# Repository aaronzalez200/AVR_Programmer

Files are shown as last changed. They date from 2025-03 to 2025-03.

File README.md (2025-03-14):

# AVR_Programmer

Small board with mounting holes that was designed to easily place an Arduino that runs software that programs an external board that contains an AVR chip via ICSP. Display included to show the user the testing process and if any errors have occurred.

Designed using KiCad

BoardTop
BoardBottom

Early prototype using Arduino MEGA later updated for UNO:

Screenshot_20250314_091232_Gallery

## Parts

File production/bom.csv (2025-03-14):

Designator | Footprint | Quantity | Value | LCSC Part #
A1 | Arduino_UNO_R3 | 1 | Arduino_UNO_R3
C1, C2 | C_Axial_L3.8mm_D2.6mm_P7.50mm_Horizontal | 2 | 0.1uF
H1, H2, H3, H4 | MountingHole_3mm | 4 | MountingHole
H5, H6, H7, H8 | Display_Mounting_Hole | 4 | Display Mounting
J1 | PinHeader_1x20_P2.54mm_Vertical | 1 | NHD-2.23-12832UCB3
J2 | IDC-Header_2x03_P2.54mm_Vertical | 1 | Programming Header
R1 | R_Axial_DIN0411_L9.9mm_D3.6mm_P12.70mm_Horizontal | 1 | 1k
R2 | R_Axial_DIN0411_L9.9mm_D3.6mm_P12.70mm_Horizontal | 1 | 10k
SW1 | TerminalBlock_bornier-2_P5.08mm | 1 | Button
U1 | TSSOP24_SOT355-1_NXP | 1 | NVT2010PW_118

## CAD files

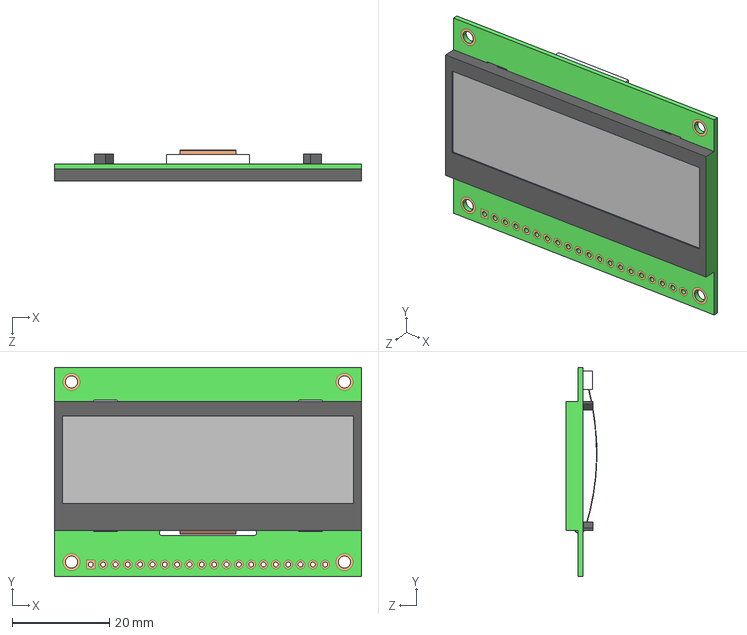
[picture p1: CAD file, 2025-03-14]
LibrariesAdded/NHD-2.23-12832U/NHD-2.23-12832U.STEP
63.2 x 43.1 x 6.37 mm

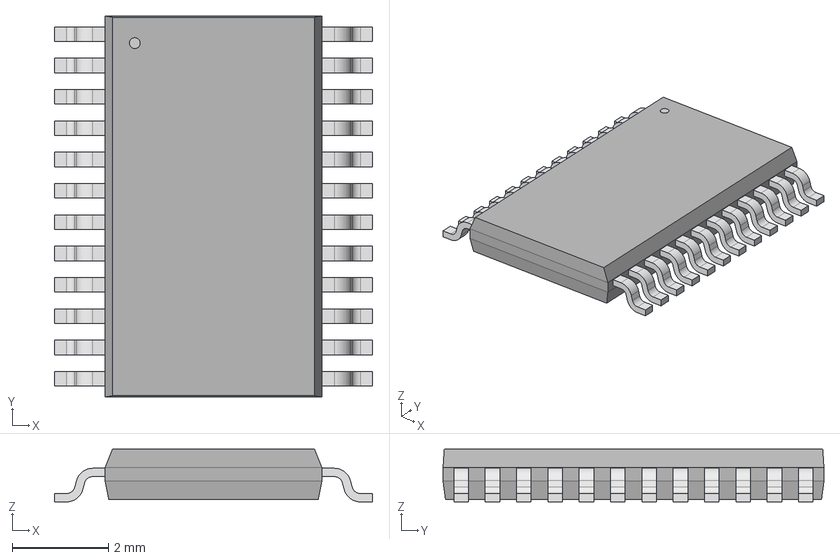
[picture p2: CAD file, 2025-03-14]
LibrariesAdded/NVT2010PW_118/TSSOP24_SOT355-1_NXP.step
6.60 x 7.90 x 1.09 mm

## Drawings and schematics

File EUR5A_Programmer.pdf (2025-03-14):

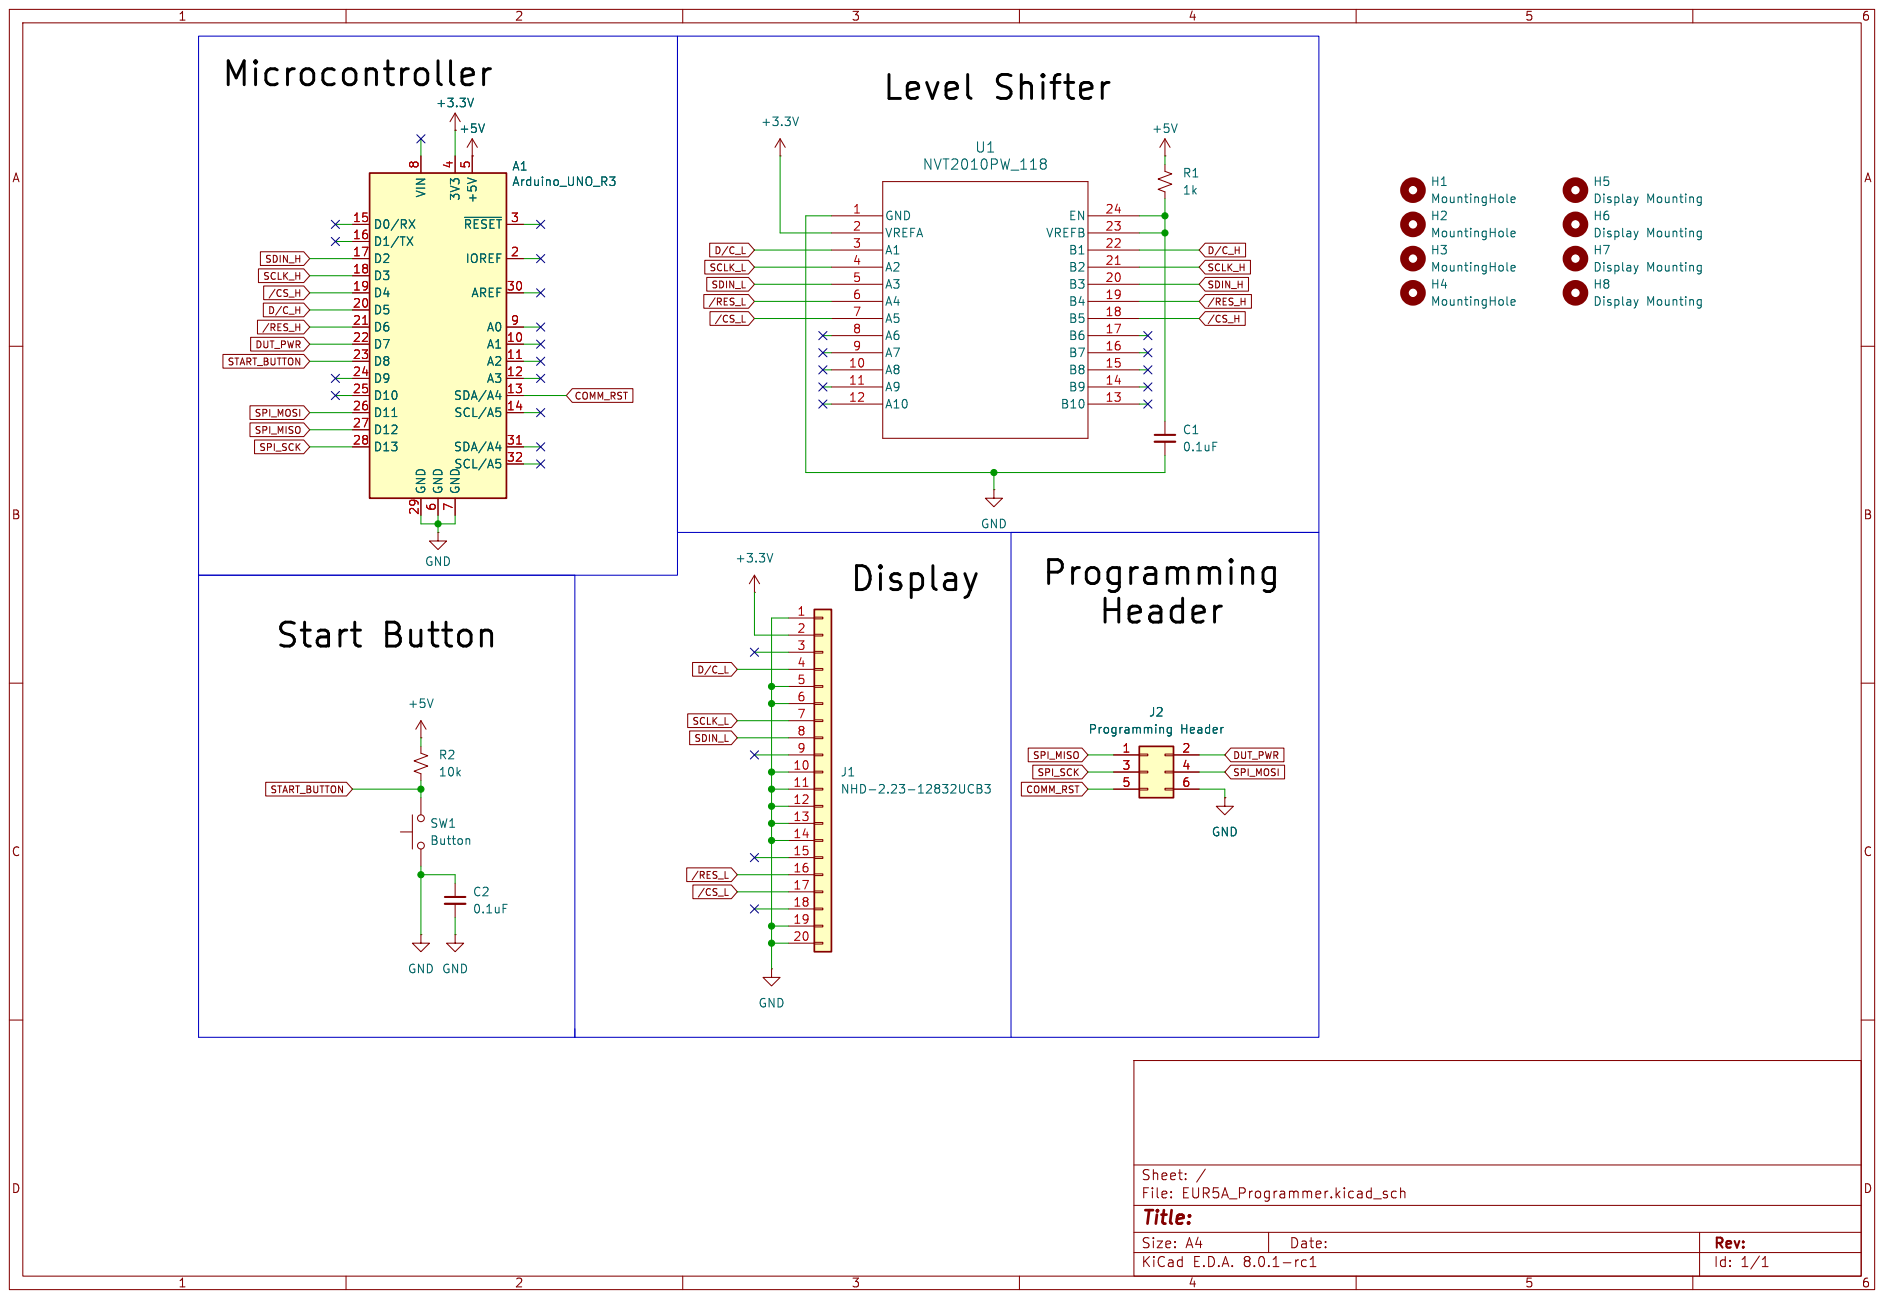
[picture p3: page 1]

Id: 1/1 Title: File: EUR5A_Programmer.kicad_sch Sheet: /

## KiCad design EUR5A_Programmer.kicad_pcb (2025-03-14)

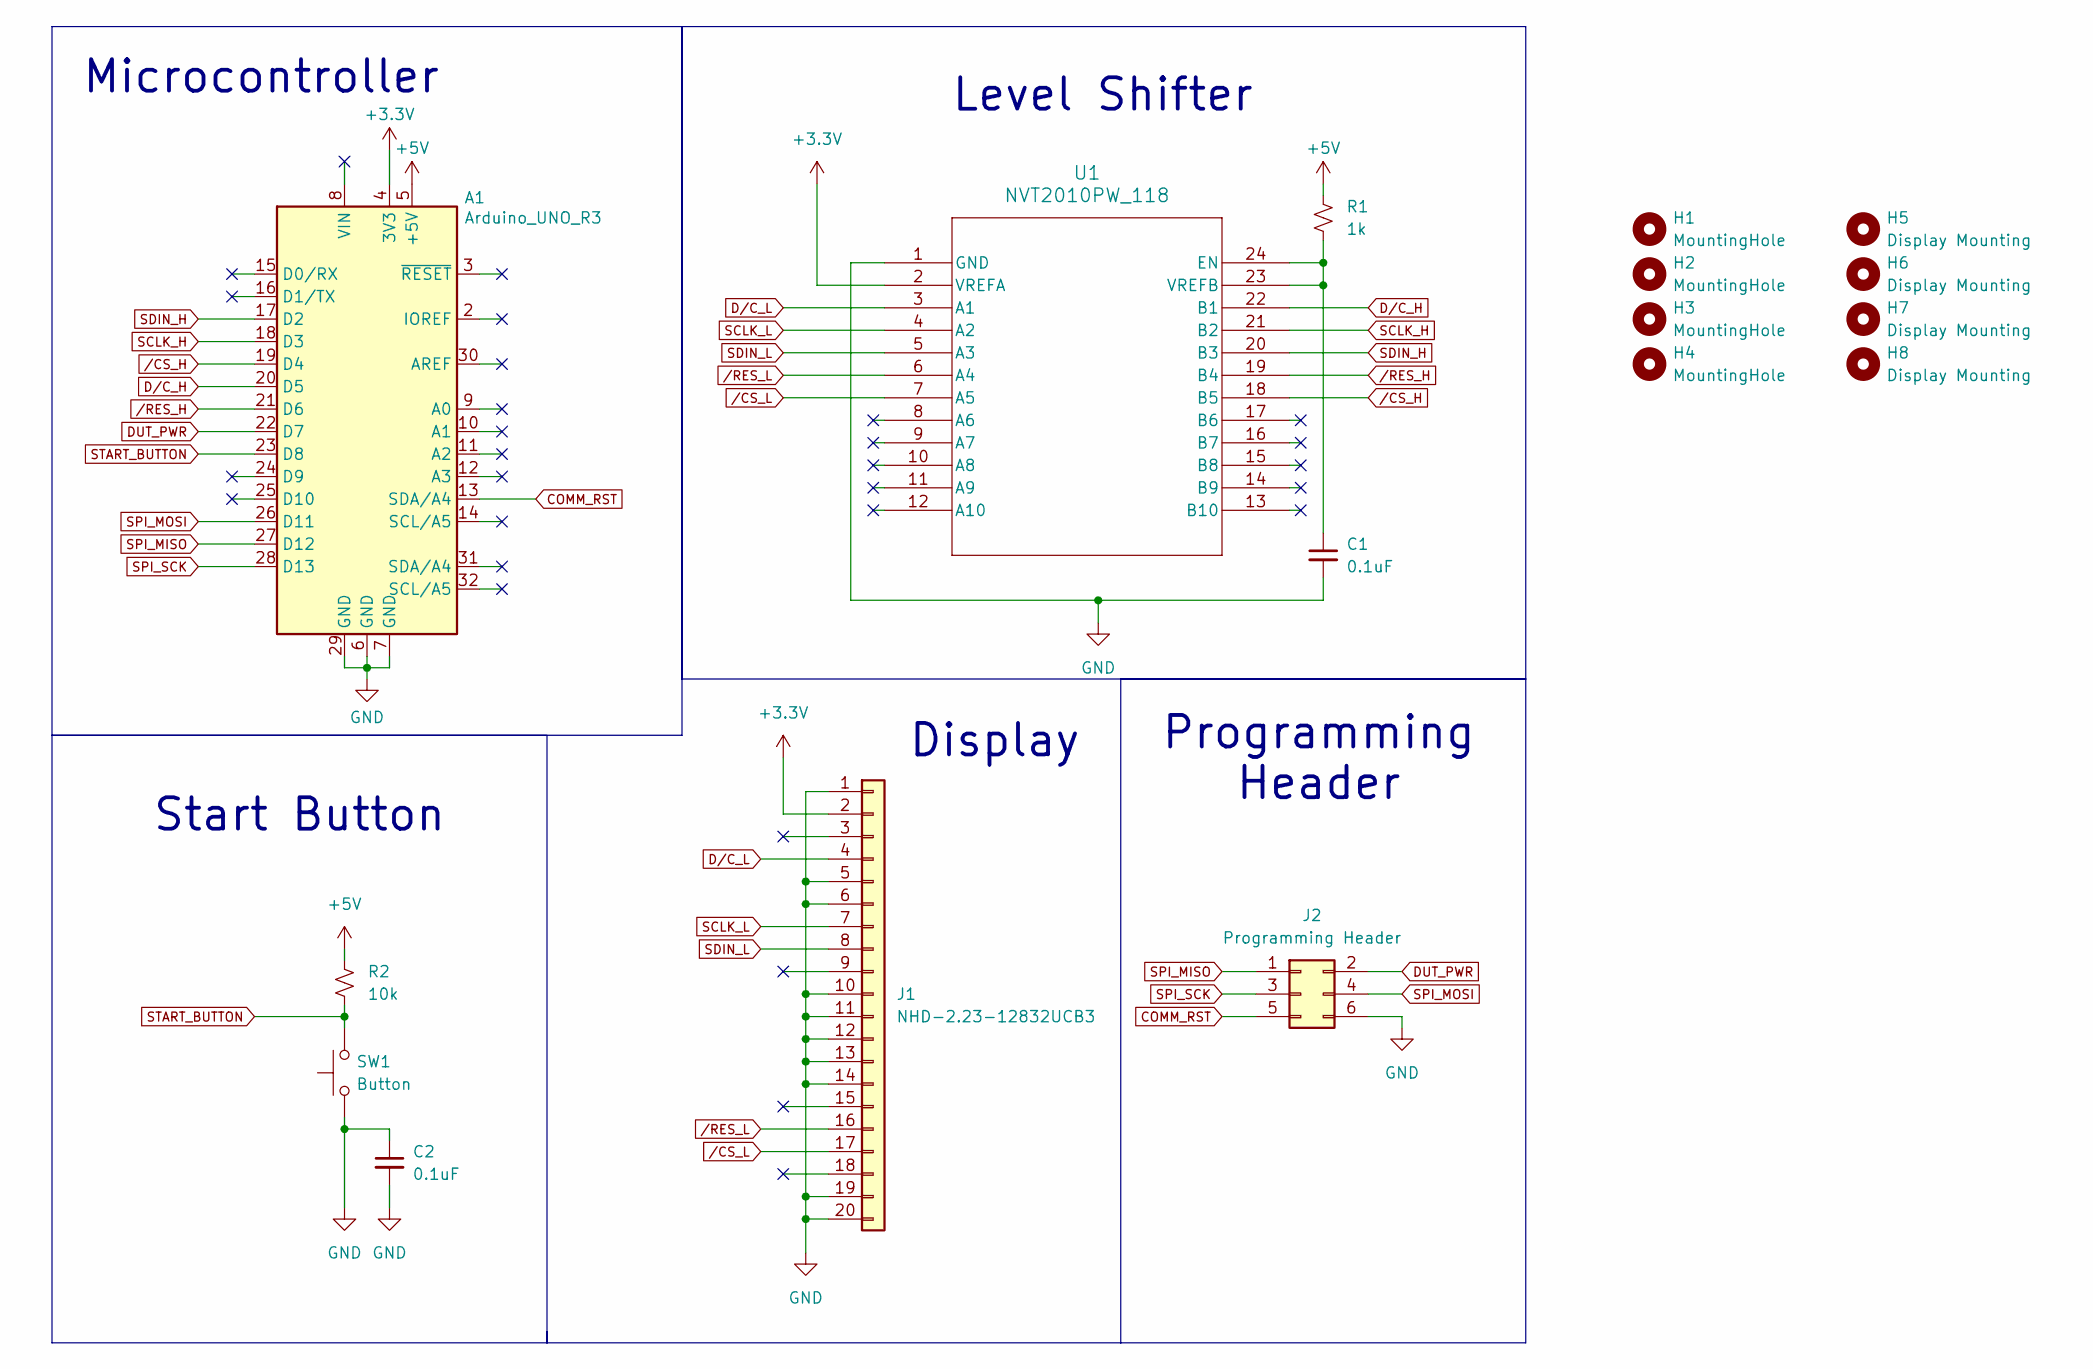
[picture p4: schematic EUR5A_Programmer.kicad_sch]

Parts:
A1: Arduino_UNO_R3
C1, C2: 0.1uF; C_Axial_L3.8mm_D2.6mm_P7.50mm_Horizontal
H1, H2, H3, H4: MountingHole; MountingHole_3mm
H5, H6, H7, H8: Display Mounting; Display_Mounting_Hole
J1: NHD-2.23-12832UCB3; PinHeader_1x20_P2.54mm_Vertical
J2: Programming Header; IDC-Header_2x03_P2.54mm_Vertical
R1: 1k; R_Axial_DIN0411_L9.9mm_D3.6mm_P12.70mm_Horizontal
R2: 10k; R_Axial_DIN0411_L9.9mm_D3.6mm_P12.70mm_Horizontal
SW1: Button; TerminalBlock_bornier-2_P5.08mm
U1: NVT2010PW_118; TSSOP24_SOT355-1_NXP

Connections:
+3.3V: A1.4 (3V3), J1.2, U1.2 (VREFA)
+5V: A1.5 (+5V), R1.1, R2.1
COMM_RST: A1.13 (SDA/A4), J2.5
DUT_PWR: A1.22 (D7), J2.2
D/C_H: A1.20 (D5), U1.22 (B1)
D/C_L: J1.4, U1.3 (A1)
GND: A1.6 (GND), A1.7 (GND), A1.29 (GND), C1.2, C2.1, C2.2, J1.1, J1.5, J1.6, J1.10, J1.11, J1.12, J1.13, J1.14, J1.19, J1.20, J2.6, SW1.1, U1.1 (GND)
unnamed: C1.1, R1.2, U1.23 (VREFB), U1.24 (EN)
SCLK_H: A1.18 (D3), U1.21 (B2)
SCLK_L: J1.7, U1.4 (A2)
SDIN_H: A1.17 (D2), U1.20 (B3)
SDIN_L: J1.8, U1.5 (A3)
SPI_MISO: A1.27 (D12), J2.1
SPI_MOSI: A1.26 (D11), J2.4
SPI_SCK: A1.28 (D13), J2.3
START_BUTTON: A1.23 (D8), R2.2, SW1.2
/CS_H: A1.19 (D4), U1.18 (B5)
/CS_L: J1.17, U1.7 (A5)
/RES_H: A1.21 (D6), U1.19 (B4)
/RES_L: J1.16, U1.6 (A4)

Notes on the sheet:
Start Button
Microcontroller
Programming Header
Display
Level Shifter

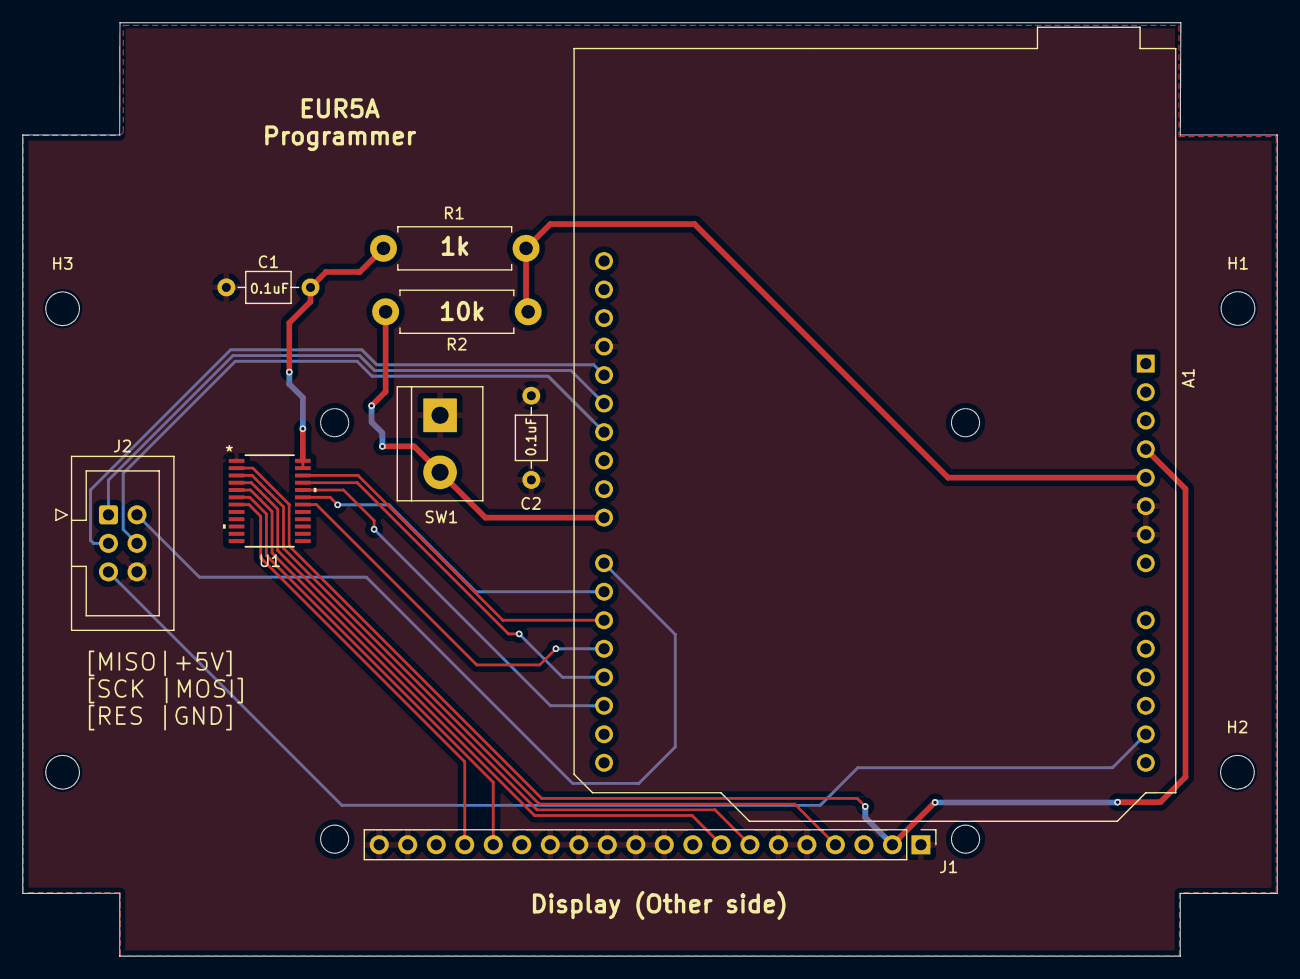
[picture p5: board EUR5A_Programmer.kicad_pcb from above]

Board: 2 copper layers, 111.8 x 83.2 mm, 17 parts (0 on the bottom side), 20 nets.

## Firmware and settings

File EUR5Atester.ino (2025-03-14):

/*
11/18/24
Rewriting NETCOM display tester code as a starting point for creating a tester
for the EUR5A. Will be programming an ATMEGA88P. 
*/

/* 
================|
Configuring I/Os|
================|
Buttons:
PB0 - Start (Input)

===================|
Configuring Display|
===================|


===============|
Configuring SPI|
===============|
Data Lines Cont'd:
PB2 - CS  (Output)
PB3 - MOSI  (Output)
PB4 - MISO  (Input)
PB5 - SCK (Output)
*/

#include <avr/pgmspace.h>
#include "program.h"

#define START_BUTTON    8
#define COMM_RST        A4

#if defined(__AVR_ATmega2560__)
    #define SPI_SCK         52
    #define SPI_MISO        50
    #define SPI_MOSI        51
    #define SPI_CS          53
    // display stuff here
    #define SDIN            46
    #define SCLK            45
    #define CS              48
    #define DC              47
    #define RES             44
    // DUT power
    #define DUT_PWR         31
#else // using UNO 
    #define SPI_SCK         13
    #define SPI_MISO        12
    #define SPI_MOSI        11
    #define SPI_CS          10
    // display stuff here
    #define SDIN            2
    #define SCLK            3
    #define CS              4
    #define DC              5
    #define RES             6
    // DUT power
    #define DUT_PWR         7
#endif


typedef struct {
  char errCode;
  const char *errMsg;
} ErrorInfo;

#define MAJOR_CODE(code) ((code >> 4) & 0x0F)
#define MINOR_CODE(code) (code & 0x0F)

#define EC_DEFAULT_OK     0
#define EC_24V_HIGH       0x10
#define EC_24V_LOW        0x11
#define EC_5V_HIGH        0x12
#define EC_5V_LOW         0x13
#define EC_3_3V_HIGH      0x14
#define EC_3_3V_LOW       0x15
#define EC_FAIL_ENTER     0x20
#define EC_WRONG_CHIP     0x21
#define EC_FAIL_VERIFY    0x22
#define EC_FAIL_FUSE      0x23
#define EC_FAIL_H_FUSE    0x24
#define EC_FAIL_X_FUSE    0x25
#define EC_FAIL_CODE_P    0x26
#define EC_USER_DECLARED  0x60
#define EC_TEST_SET_ERR   0x70
 
const char errmsg10[] = "ERR #1.0: 24V too HIGH";
const char errmsg11[] = "ERR #1.1: 24V too LOW";
const char errmsg12[] = "ERR #1.2: 5V too HIGH";
const char errmsg13[] = "ERR #1.3: 5V too LOW";
const char errmsg14[] = "ERR #1.4: 3.3V too HIGH";
const char errmsg15[] = "ERR #1.5: 3.3V too LOW";
const char errmsg20[] = "ERR #2.0: Chip did not return 0x53; Unable to write to Chip";
const char errmsg21[] = "ERR #2.1: Chip ID is incorrect; Wrong Chip on DUT";
const char errmsg22[] = "ERR #2.2: Failed to verify program";
const char errmsg23[] = "ERR #2.3: Failed to write to FUSE";
const char errmsg24[] = "ERR #2.4: Failed to write to H FUSE";
const char errmsg25[] = "ERR #2.5: Failed to write to X FUSE";
const char errmsg26[] = "ERR #2.6:  Failed to verify code protection";
const char errmsg60[] = "ERR #6.0: User declared error";
const char errmsg70[] = "ERR #7.0: Test Set Error; Relay is ON already before user begins test";

ErrorInfo errorTable[] = {
  {EC_24V_HIGH, errmsg10},
  {EC_24V_LOW, errmsg11},
  {EC_5V_HIGH, errmsg12},
  {EC_5V_LOW, errmsg13},
  {EC_3_3V_HIGH, errmsg14},
  {EC_3_3V_LOW, errmsg15},
  {EC_FAIL_ENTER, errmsg20},
  {EC_WRONG_CHIP, errmsg21},
  {EC_FAIL_VERIFY, errmsg22},
  {EC_FAIL_FUSE, errmsg23},
  {EC_FAIL_H_FUSE, errmsg24},
  {EC_FAIL_X_FUSE, errmsg25},
  {EC_FAIL_CODE_P, errmsg26},
  {EC_USER_DECLARED, errmsg60},
  {EC_TEST_SET_ERR, errmsg70}
};

/****************************************************
*             Hex Table for Example Image           *
*****************************************************/
const unsigned char startScreen[512] PROGMEM = {
0x00, 0x00, 0x00, 0x00, 0x00, 0x00, 0x00, 0x00, 0x00, 0x00, 0x00, 0x00, 0x00, 0x00, 0x00, 0x00,
0x00, 0x00, 0x00, 0x00, 0x00, 0x00, 0x00, 0x00, 0x00, 0x00, 0x00, 0x00, 0x00, 0x00, 0x00, 0x00,
0x00, 0x00, 0x00, 0x00, 0x00, 0x00, 0x00, 0x00, 0x00, 0x00, 0x00, 0x00, 0x00, 0x00, 0x00, 0x00,
0x00, 0x00, 0x00, 0x00, 0x00, 0x00, 0x00, 0x00, 0x00, 0x00, 0x00, 0x00, 0x00, 0x00, 0x00, 0x00,
0x00, 0x00, 0x00, 0x00, 0x00, 0x00, 0x00, 0x00, 0x00, 0x00, 0x00, 0x00, 0x00, 0x00, 0x00, 0x00,
0x00, 0x00, 0x00, 0x00, 0x00, 0x00, 0x00, 0x00, 0x00, 0x00, 0x00, 0x00, 0x00, 0x00, 0x00, 0x00,
0x00, 0x00, 0x00, 0x00, 0x00, 0x00, 0x00, 0x00, 0x00, 0x00, 0x00, 0x00, 0x00, 0x00, 0x00, 0x00,
0x00, 0x00, 0x00, 0x00, 0x00, 0x00, 0x00, 0x00, 0x00, 0x00, 0x00, 0x00, 0x00, 0x00, 0x00, 0x00,
0x00, 0x00, 0x00, 0x00, 0x00, 0x00, 0x00, 0x00, 0x00, 0xF8, 0xF8, 0x88, 0x88, 0x08, 0x08, 0x00,
0xF8, 0xF8, 0x00, 0x00, 0xF8, 0xF8, 0x00, 0xF8, 0xF8, 0x88, 0x88, 0xF8, 0x70, 0x00, 0x78, 0x78,
0x48, 0x48, 0xC8, 0x88, 0x00, 0xF0, 0xF8, 0x08, 0x08, 0xF8, 0xF0, 0x00, 0x00, 0x00, 0x00, 0x00,
0x00, 0xF8, 0xF8, 0x88, 0x88, 0xF8, 0x70, 0x00, 0xE0, 0xE0, 0x80, 0x40, 0x60, 0x60, 0x00, 0xC0,
0xE0, 0x20, 0x20, 0xE0, 0xC0, 0x00, 0xC0, 0xE0, 0x20, 0x20, 0xE0, 0xE0, 0x00, 0xE0, 0xE0, 0x80,
0x40, 0x60, 0x60, 0x00, 0x40, 0x60, 0x20, 0x20, 0xE0, 0xC0, 0x00, 0xE0, 0xE0, 0x20, 0xC0, 0x20,
0xE0, 0xC0, 0x00, 0xE0, 0xE0, 0x20, 0xC0, 0x20, 0xE0, 0xC0, 0x00, 0xC0, 0xE0, 0x20, 0x20, 0xE0,
0xC0, 0x00, 0xE0, 0xE0, 0x80, 0x40, 0x60, 0x60, 0x00, 0x00, 0x00, 0x00, 0x00, 0x00, 0x00, 0x00,
0x00, 0x00, 0x00, 0x00, 0x00, 0x00, 0x00, 0x00, 0x00, 0x0F, 0x0F, 0x08, 0x08, 0x08, 0x08, 0x00,
0x07, 0x0F, 0x08, 0x08, 0x0F, 0x07, 0x00, 0x0F, 0x0F, 0x01, 0x03, 0x0E, 0x0C, 0x00, 0x04, 0x0C,
0x08, 0x08, 0x0F, 0x07, 0x00, 0x0F, 0x0F, 0x01, 0x01, 0x0F, 0x0F, 0x00, 0x00, 0x00, 0x00, 0x00,
0x00, 0x0F, 0x0F, 0x00, 0x00, 0x00, 0x00, 0x00, 0x0F, 0x0F, 0x00, 0x00, 0x00, 0x00, 0x00, 0x07,
0x0F, 0x08, 0x08, 0x0F, 0x07, 0x00, 0x13, 0x37, 0x24, 0x24, 0x3F, 0x1F, 0x00, 0x0F, 0x0F, 0x00,
0x00, 0x00, 0x00, 0x00, 0x06, 0x0E, 0x09, 0x09, 0x0F, 0x0F, 0x00, 0x0F, 0x0F, 0x00, 0x03, 0x00,
0x0F, 0x0F, 0x00, 0x0F, 0x0F, 0x00, 0x03, 0x00, 0x0F, 0x0F, 0x00, 0x07, 0x0F, 0x09, 0x09, 0x0D,
0x05, 0x00, 0x0F, 0x0F, 0x00, 0x00, 0x00, 0x00, 0x00, 0x00, 0x00, 0x00, 0x00, 0x00, 0x00, 0x00,
0x00, 0x00, 0x00, 0x00, 0x00, 0x00, 0x00, 0x00, 0x00, 0x00, 0x00, 0x00, 0x00, 0x00, 0x00, 0x00,
0x00, 0x00, 0x00, 0x00, 0x00, 0x00, 0x00, 0x00, 0x00, 0x00, 0x00, 0x00, 0x00, 0x00, 0x00, 0x00,
0x00, 0x00, 0x00, 0x00, 0x00, 0x00, 0x00, 0x00, 0x00, 0x00, 0x00, 0x00, 0x00, 0x00, 0x00, 0x00,
0x00, 0x00, 0x00, 0x00, 0x00, 0x00, 0x00, 0x00, 0x00, 0x00, 0x00, 0x00, 0x00, 0x00, 0x00, 0x00,
0x00, 0x00, 0x00, 0x00, 0x00, 0x00, 0x00, 0x00, 0x00, 0x00, 0x00, 0x00, 0x00, 0x00, 0x00, 0x00,
0x00, 0x00, 0x00, 0x00, 0x00, 0x00, 0x00, 0x00, 0x00, 0x00, 0x00, 0x00, 0x00, 0x00, 0x00, 0x00,
0x00, 0x00, 0x00, 0x00, 0x00, 0x00, 0x00, 0x00, 0x00, 0x00, 0x00, 0x00, 0x00, 0x00, 0x00, 0x00,
0x00, 0x00, 0x00, 0x00, 0x00, 0x00, 0x00, 0x00, 0x00, 0x00, 0x00, 0x00, 0x00, 0x00, 0x00, 0x00
};


const unsigned char Phase1 [512] PROGMEM = {
0x00, 0x00, 0x00, 0x00, 0x00, 0x00, 0x00, 0x00, 0x00, 0x00, 0x00, 0x00, 0x00, 0x00, 0x00, 0x00,
0x00, 0x00, 0x00, 0x00, 0x00, 0x00, 0x00, 0x00, 0x00, 0x00, 0x00, 0x00, 0x00, 0x00, 0x00, 0x00,
0x00, 0x00, 0x00, 0x00, 0x00, 0x00, 0x00, 0x00, 0x00, 0x00, 0x00, 0x00, 0x00, 0x00, 0x00, 0x00,
0x00, 0x00, 0x00, 0x00, 0x00, 0x00, 0x00, 0x00, 0x00, 0x00, 0x00, 0x00, 0x00, 0x00, 0x00, 0x00,
0x00, 0x00, 0x00, 0x00, 0x00, 0x00, 0x00, 0x00, 0x00, 0x00, 0x00, 0x00, 0x00, 0x00, 0x00, 0x00,
0x00, 0x00, 0x00, 0x00, 0x00, 0x00, 0x00, 0x00, 0x00, 0x00, 0x00, 0x00, 0x00, 0x00, 0x00, 0x00,
0x00, 0x00, 0x00, 0x00, 0x00, 0x00, 0x00, 0x00, 0x00, 0x00, 0x00, 0x00, 0x00, 0x00, 0x00, 0x00,
0x00, 0x00, 0x00, 0x00, 0x00, 0x00, 0x00, 0x00, 0x00, 0x00, 0x00, 0x00, 0x00, 0x00, 0x00, 0x00,
0x00, 0x00, 0x00, 0x00, 0x00, 0x00, 0x00, 0x00, 0x00, 0xF8, 0xF8, 0x88, 0x88, 0xF8, 0x70, 0x00,
0xE0, 0xE0, 0x80, 0x40, 0x60, 0x60, 0x00, 0xC0, 0xE0, 0x20, 0x20, 0xE0, 0xC0, 0x00, 0xC0, 0xE0,
0x20, 0x20, 0x60, 0x40, 0x00, 0xC0, 0xE0, 0x20, 0x20, 0x60, 0x40, 0x00, 0x00, 0x00, 0x00, 0x00,
0x00, 0x00, 0x00, 0x00, 0x00, 0x00, 0x00, 0x00, 0x00, 0x00, 0x00, 0x00, 0x00, 0x00, 0x70, 0xF8,
0x88, 0x88, 0x98, 0x10, 0x00, 0x20, 0xF0, 0xF0, 0x20, 0x20, 0x00, 0x40, 0x60, 0x20, 0x20, 0xE0,
0xC0, 0x00, 0xE0, 0xE0, 0x80, 0xC0, 0x60, 0x60, 0x00, 0x20, 0xF0, 0xF0, 0x20, 0x20, 0x00, 0x00,
0x80, 0x80, 0x80, 0x80, 0x00, 0x80, 0x80, 0x80, 0x80, 0x00, 0x00, 0x20, 0x60, 0xC0, 0x80, 0x00,
0x00, 0x00, 0x00, 0x00, 0x00, 0x00, 0x00, 0x00, 0x00, 0x00, 0x00, 0x00, 0x00, 0x00, 0x00, 0x00,
0x00, 0x00, 0x00, 0x00, 0x00, 0x00, 0x00, 0x00, 0x00, 0x0F, 0x0F, 0x00, 0x00, 0x00, 0x00, 0x00,
0x0F, 0x0F, 0x00, 0x00, 0x00, 0x00, 0x00, 0x07, 0x0F, 0x09, 0x09, 0x0D, 0x05, 0x00, 0x04, 0x0D,
0x09, 0x09, 0x0F, 0x06, 0x00, 0x04, 0x0D, 0x09, 0x09, 0x0F, 0x06, 0x00, 0x00, 0x00, 0x00, 0x00,
0x00, 0x00, 0x00, 0x00, 0x00, 0x00, 0x00, 0x00, 0x00, 0x00, 0x00, 0x00, 0x00, 0x00, 0x04, 0x0C,
0x08, 0x08, 0x0F, 0x07, 0x00, 0x00, 0x07, 0x0F, 0x08, 0x08, 0x00, 0x06, 0x0E, 0x09, 0x09, 0x0F,
0x0F, 0x00, 0x0F, 0x0F, 0x00, 0x00, 0x00, 0x00, 0x00, 0x00, 0x07, 0x0F, 0x08, 0x08, 0x00, 0x00,
0x00, 0x00, 0x00, 0x00, 0x00, 0x00, 0x00, 0x00, 0x00, 0x00, 0x00, 0x02, 0x03, 0x01, 0x00, 0x00,
0x00, 0x00, 0x00, 0x00, 0x00, 0x00, 0x00, 0x00, 0x00, 0x00, 0x00, 0x00, 0x00, 0x00, 0x00, 0x00,
0x00, 0x00, 0x00, 0x00, 0x00, 0x00, 0x00, 0x00, 0x00, 0x00, 0x00, 0x00, 0x00, 0x00, 0x00, 0x00,
0x00, 0x00, 0x00, 0x00, 0x00, 0x00, 0x00, 0x00, 0x00, 0x00, 0x00, 0x00, 0x00, 0x00, 0x00, 0x00,
0x00, 0x00, 0x00, 0x00, 0x00, 0x00, 0x00, 0x00, 0x00, 0x00, 0x00, 0x00, 0x00, 0x00, 0x00, 0x00,
0x00, 0x00, 0x00, 0x00, 0x00, 0x00, 0x00, 0x00, 0x00, 0x00, 0x00, 0x00, 0x00, 0x00, 0x00, 0x00,
0x00, 0x00, 0x00, 0x00, 0x00, 0x00, 0x00, 0x00, 0x00, 0x00, 0x00, 0x00, 0x00, 0x00, 0x00, 0x00,
0x00, 0x00, 0x00, 0x00, 0x00, 0x00, 0x00, 0x00, 0x00, 0x00, 0x00, 0x00, 0x00, 0x00, 0x00, 0x00,
0x00, 0x00, 0x00, 0x00, 0x00, 0x00, 0x00, 0x00, 0x00, 0x00, 0x00, 0x00, 0x00, 0x00, 0x00, 0x00,
0x00, 0x00, 0x00, 0x00, 0x00, 0x00, 0x00, 0x00, 0x00, 0x00, 0x00, 0x00, 0x00, 0x00, 0x00, 0x00
};

const unsigned char Phase2 [512] PROGMEM = {
0x00, 0x00, 0x00, 0x00, 0xF8, 0xF8, 0x88, 0x88, 0xF8, 0x70, 0x00, 0xE0, 0xE0, 0x80, 0x40, 0x60,
0x60, 0x00, 0xC0, 0xE0, 0x20, 0x20, 0xE0, 0xC0, 0x00, 0xC0, 0xE0, 0x20, 0x20, 0xE0, 0xE0, 0x00,
0x00, 0x00, 0x00, 0x00, 0x00, 0x00, 0x00, 0x00, 0x00, 0x00, 0xF8, 0xF8, 0x88, 0x88, 0x88, 0x08,
0x08, 0x00, 0xE0, 0xE0, 0x20, 0x20, 0xE0, 0xC0, 0x00, 0x40, 0x60, 0x20, 0x20, 0xE0, 0xC0, 0x00,
0xF8, 0xF8, 0x20, 0x20, 0xE0, 0xC0, 0x00, 0xF8, 0xF8, 0x00, 0x00, 0xC0, 0xE0, 0x20, 0x20, 0xE0,
0xC0, 0x00, 0x00, 0x00, 0x00, 0x00, 0x00, 0x00, 0x00, 0x00, 0x00, 0x00, 0x00, 0x00, 0x00, 0x00,
0x00, 0x00, 0x00, 0x00, 0x00, 0x00, 0x00, 0x00, 0x00, 0x00, 0x00, 0x00, 0x00, 0x00, 0x00, 0xF8,
0x08, 0x08, 0x08, 0x08, 0x08, 0x08, 0x08, 0xF8, 0x00, 0x00, 0x00, 0x00, 0x00, 0x00, 0x00, 0x00,
0x00, 0x00, 0x00, 0x00, 0x0F, 0x0F, 0x00, 0x00, 0x00, 0x00, 0x00, 0x0F, 0x0F, 0x00, 0x00, 0x00,
0x00, 0x00, 0x07, 0x0F, 0x08, 0x08, 0x0F, 0x07, 0x00, 0x13, 0x37, 0x24, 0x24, 0x3F, 0x1F, 0x00,
0x18, 0x18, 0x00, 0x00, 0x00, 0x00, 0x00, 0x00, 0x00, 0x00, 0x0F, 0x0F, 0x08, 0x08, 0x08, 0x08,
0x08, 0x00, 0x0F, 0x0F, 0x00, 0x00, 0x0F, 0x0F, 0x00, 0x06, 0x0E, 0x09, 0x09, 0x0F, 0x0F, 0x00,
0x0F, 0x0F, 0x08, 0x08, 0x0F, 0x07, 0x00, 0x07, 0x0F, 0x08, 0x00, 0x07, 0x0F, 0x09, 0x09, 0x0D,
0x05, 0x00, 0x00, 0x00, 0x00, 0x00, 0x00, 0x00, 0x00, 0x00, 0x00, 0x00, 0x00, 0x00, 0x00, 0x00,
0x00, 0x00, 0x00, 0x00, 0x00, 0x00, 0x00, 0x00, 0x00, 0x00, 0x00, 0x00, 0x00, 0x00, 0x00, 0x0F,
0x08, 0x08, 0x08, 0x08, 0x08, 0x08, 0x08, 0x0F, 0x00, 0x00, 0x00, 0x00, 0x00, 0x00, 0x00, 0x00,
0x00, 0x00, 0x00, 0x00, 0xF8, 0xF8, 0x00, 0x00, 0xF8, 0xF8, 0x00, 0xC0, 0xE0, 0x20, 0x20, 0xE0,
0xC0, 0x00, 0xE0, 0xE0, 0x80, 0x80, 0x40, 0x60, 0x60, 0x00, 0xE8, 0xE8, 0x00, 0x40, 0xF0, 0xF8,
0x48, 0x48, 0x00, 0xE0, 0xE0, 0x00, 0x00, 0xE0, 0xE0, 0x00, 0x00, 0x00, 0x00, 0x00, 0x00, 0x00,
0x00, 0x00, 0xF0, 0xF8, 0x08, 0x08, 0x18, 0x10, 0x00, 0xF8, 0xF8, 0x20, 0x20, 0xE0, 0xC0, 0x00,
0x00, 0xE8, 0xE8, 0x00, 0xE0, 0xE0, 0x20, 0x20, 0xE0, 0xC0, 0x00, 0x00, 0x00, 0x00, 0x00, 0x00,
0x00, 0x00, 0xF8, 0xF8, 0x00, 0xF8, 0xF8, 0x08, 0x08, 0xF8, 0xF0, 0x00, 0x00, 0x00, 0x00, 0x00,
0x00, 0x00, 0x00, 0x00, 0x00, 0x00, 0x00, 0x00, 0x00, 0x00, 0x00, 0x00, 0x00, 0x00, 0x00, 0xF8,
0x08, 0x08, 0x08, 0x08, 0x08, 0x08, 0x08, 0xF8, 0x00, 0x00, 0x00, 0x00, 0x00, 0x00, 0x00, 0x00,
0x00, 0x00, 0x00, 0x00, 0x03, 0x07, 0x0C, 0x0C, 0x07, 0x03, 0x00, 0x07, 0x0F, 0x09, 0x09, 0x0D,
0x05, 0x00, 0x0F, 0x0F, 0x00, 0x00, 0x00, 0x00, 0x00, 0x00, 0x0F, 0x0F, 0x00, 0x00, 0x0F, 0x0F,
0x00, 0x00, 0x00, 0x13, 0x37, 0x24, 0x24, 0x3F, 0x1F, 0x00, 0x00, 0x00, 0x00, 0x00, 0x00, 0x00,
0x00, 0x00, 0x07, 0x0F, 0x08, 0x08, 0x0C, 0x04, 0x00, 0x0F, 0x0F, 0x00, 0x00, 0x0F, 0x0F, 0x00,
0x00, 0x0F, 0x0F, 0x00, 0x3F, 0x3F, 0x08, 0x08, 0x0F, 0x07, 0x00, 0x00, 0x00, 0x00, 0x00, 0x00,
0x00, 0x00, 0x0F, 0x0F, 0x00, 0x0F, 0x0F, 0x08, 0x08, 0x0F, 0x07, 0x00, 0x00, 0x00, 0x00, 0x00,
0x00, 0x00, 0x00, 0x00, 0x00, 0x00, 0x00, 0x00, 0x00, 0x00, 0x00, 0x00, 0x00, 0x00, 0x00, 0x0F,
0x08, 0x08, 0x08, 0x08, 0x08, 0x08, 0x08, 0x0F, 0x00, 0x00, 0x00, 0x00, 0x00, 0x00, 0x00, 0x00
};


const unsigned char Phase3 [512] PROGMEM = {
0x00, 0x00, 0x00, 0x00, 0xF8, 0xF8, 0x88, 0x88, 0xF8, 0x70, 0x00, 0xE0, 0xE0, 0x80, 0x40, 0x60,
0x60, 0x00, 0xC0, 0xE0, 0x20, 0x20, 0xE0, 0xC0, 0x00, 0xC0, 0xE0, 0x20, 0x20, 0xE0, 0xE0, 0x00,
0xE0, 0xE0, 0x80, 0x80, 0x40, 0x60, 0x60, 0x00, 0x40, 0x60, 0x20, 0x20, 0xE0, 0xC0, 0x00, 0xE0,
0xE0, 0x20, 0xC0, 0x20, 0xE0, 0xC0, 0x00, 0x00, 0x00, 0x00, 0x00, 0x00, 0x00, 0x00, 0xF0, 0xF8,
0x08, 0x08, 0x18, 0x10, 0x00, 0xF8, 0xF8, 0x20, 0x20, 0xE0, 0xC0, 0x00, 0x00, 0xE8, 0xE8, 0x00,
0xE0, 0xE0, 0x20, 0x20, 0xE0, 0xC0, 0x00, 0x00, 0x00, 0x00, 0x00, 0x00, 0x00, 0x00, 0x00, 0x00,
0x00, 0x00, 0x00, 0x00, 0x00, 0x00, 0x00, 0x00, 0x00, 0x00, 0x00, 0x00, 0x00, 0x00, 0x00, 0xF8,
0x08, 0x08, 0x08, 0x08, 0x08, 0x08, 0x08, 0xF8, 0x00, 0x00, 0x00, 0x00, 0x00, 0x00, 0x00, 0x00,
0x00, 0x00, 0x00, 0x00, 0x0F, 0x0F, 0x00, 0x00, 0x00, 0x00, 0x00, 0x0F, 0x0F, 0x00, 0x00, 0x00,
0x00, 0x00, 0x07, 0x0F, 0x08, 0x08, 0x0F, 0x07, 0x00, 0x13, 0x37, 0x24, 0x24, 0x3F, 0x1F, 0x00,
0x0F, 0x0F, 0x00, 0x00, 0x00, 0x00, 0x00, 0x00, 0x06, 0x0E, 0x09, 0x09, 0x0F, 0x0F, 0x00, 0x0F,
0x0F, 0x00, 0x03, 0x00, 0x0F, 0x0F, 0x00, 0x00, 0x00, 0x00, 0x00, 0x00, 0x00, 0x00, 0x07, 0x0F,
0x08, 0x08, 0x0C, 0x04, 0x00, 0x0F, 0x0F, 0x00, 0x00, 0x0F, 0x0F, 0x00, 0x00, 0x0F, 0x0F, 0x00,
0x3F, 0x3F, 0x08, 0x08, 0x0F, 0x07, 0x00, 0x00, 0x00, 0x00, 0x00, 0x00, 0x00, 0x00, 0x00, 0x00,
0x00, 0x00, 0x00, 0x00, 0x00, 0x00, 0x00, 0x00, 0x00, 0x00, 0x00, 0x00, 0x00, 0x00, 0x00, 0x0F,
0x08, 0x08, 0x08, 0x08, 0x08, 0x08, 0x08, 0x0F, 0x00, 0x00, 0x00, 0x00, 0x00, 0x00, 0x00, 0x00,
0x00, 0x00, 0x00, 0x00, 0xF8, 0xF8, 0x00, 0x00, 0xF8, 0xF8, 0x00, 0xC0, 0xE0, 0x20, 0x20, 0xE0,
0xC0, 0x00, 0xE0, 0xE0, 0x80, 0x80, 0x40, 0x60, 0x60, 0x00, 0xE8, 0xE8, 0x00, 0x40, 0xF0, 0xF8,
0x48, 0x48, 0x00, 0xE0, 0xE0, 0x00, 0x00, 0xE0, 0xE0, 0x00, 0x00, 0x00, 0x00, 0x00, 0x00, 0x00,
0x00, 0xF8, 0xF8, 0x88, 0x88, 0xF8, 0x70, 0x00, 0xE0, 0xE0, 0x80, 0x40, 0x60, 0x60, 0x00, 0xC0,
0xE0, 0x20, 0x20, 0xE0, 0xC0, 0x00, 0xC0, 0xE0, 0x20, 0x20, 0xE0, 0xE0, 0x00, 0xE0, 0xE0, 0x80,
0x80, 0x40, 0x60, 0x60, 0x00, 0x40, 0x60, 0x20, 0x20, 0xE0, 0xC0, 0x00, 0xE0, 0xE0, 0x20, 0xC0,
0x20, 0xE0, 0xC0, 0x00, 0x00, 0x00, 0x00, 0x00, 0x00, 0x00, 0x00, 0x00, 0x00, 0x00, 0x00, 0xF8,
0x08, 0x08, 0x08, 0x08, 0x08, 0x08, 0x08, 0xF8, 0x00, 0x00, 0x00, 0x00, 0x00, 0x00, 0x00, 0x00,
0x00, 0x00, 0x00, 0x00, 0x03, 0x07, 0x0C, 0x0C, 0x07, 0x03, 0x00, 0x07, 0x0F, 0x09, 0x09, 0x0D,
0x05, 0x00, 0x0F, 0x0F, 0x00, 0x00, 0x00, 0x00, 0x00, 0x00, 0x0F, 0x0F, 0x00, 0x00, 0x0F, 0x0F,
0x00, 0x00, 0x00, 0x13, 0x37, 0x24, 0x24, 0x3F, 0x1F, 0x00, 0x00, 0x00, 0x00, 0x00, 0x00, 0x00,
0x00, 0x0F, 0x0F, 0x00, 0x00, 0x00, 0x00, 0x00, 0x0F, 0x0F, 0x00, 0x00, 0x00, 0x00, 0x00, 0x07,
0x0F, 0x08, 0x08, 0x0F, 0x07, 0x00, 0x13, 0x37, 0x24, 0x24, 0x3F, 0x1F, 0x00, 0x0F, 0x0F, 0x00,
0x00, 0x00, 0x00, 0x00, 0x00, 0x06, 0x0E, 0x09, 0x09, 0x0F, 0x0F, 0x00, 0x0F, 0x0F, 0x00, 0x03,
0x00, 0x0F, 0x0F, 0x00, 0x00, 0x00, 0x00, 0x00, 0x00, 0x00, 0x00, 0x00, 0x00, 0x00, 0x00, 0x0F,
0x08, 0x08, 0x08, 0x08, 0x08, 0x08, 0x08, 0x0F, 0x00, 0x00, 0x00, 0x00, 0x00, 0x00, 0x00, 0x00
};


const unsigned char Phase4 [512] PROGMEM = {
0x00, 0x00, 0x00, 0x00, 0x70, 0xF8, 0x88, 0x88, 0x98, 0x10, 0x00, 0xC0, 0xE0, 0x20, 0x20, 0xE0,
0xC0, 0x00, 0x20, 0xF0, 0xF0, 0x20, 0x20, 0x00, 0x00, 0x00, 0x00, 0x00, 0x00, 0x00, 0x00, 0xF8,
0xF8, 0x88, 0x88, 0x08, 0x08, 0x00, 0xE0, 0xE0, 0x00, 0x00, 0xE0, 0xE0, 0x00, 0xC0, 0xE0, 0x20,
0x20, 0x60, 0x40, 0x00, 0xC0, 0xE0, 0x20, 0x20, 0xE0, 0xC0, 0x00, 0xC0, 0xE0, 0x20, 0x20, 0x60,
0x40, 0x00, 0x00, 0x00, 0x00, 0x00, 0x00, 0x00, 0x00, 0x00, 0x00, 0x00, 0x00, 0x00, 0x00, 0x00,
0x00, 0x00, 0x00, 0x00, 0x00, 0x00, 0x00, 0x00, 0x00, 0x00, 0x00, 0x00, 0x00, 0x00, 0x00, 0x00,
0x00, 0x00, 0x00, 0x00, 0x00, 0x00, 0x00, 0x00, 0x00, 0x00, 0x00, 0x00, 0x00, 0x00, 0x00, 0xF8,
0x08, 0x08, 0x08, 0x08, 0x08, 0x08, 0x08, 0xF8, 0x00, 0x00, 0x00, 0x00, 0x00, 0x00, 0x00, 0x00,
0x00, 0x00, 0x00, 0x00, 0x04, 0x0C, 0x08, 0x08, 0x0F, 0x07, 0x00, 0x07, 0x0F, 0x09, 0x09, 0x0D,
0x05, 0x00, 0x00, 0x07, 0x0F, 0x08, 0x08, 0x00, 0x00, 0x00, 0x00, 0x00, 0x00, 0x00, 0x00, 0x0F,
0x0F, 0x00, 0x00, 0x00, 0x00, 0x00, 0x07, 0x0F, 0x08, 0x08, 0x0F, 0x07, 0x00, 0x04, 0x0D, 0x09,
0x09, 0x0F, 0x06, 0x00, 0x07, 0x0F, 0x09, 0x09, 0x0D, 0x05, 0x00, 0x04, 0x0D, 0x09, 0x09, 0x0F,
0x06, 0x00, 0x00, 0x00, 0x00, 0x00, 0x00, 0x00, 0x00, 0x00, 0x00, 0x00, 0x00, 0x00, 0x00, 0x00,
0x00, 0x00, 0x00, 0x00, 0x00, 0x00, 0x00, 0x00, 0x00, 0x00, 0x00, 0x00, 0x00, 0x00, 0x00, 0x00,
0x00, 0x00, 0x00, 0x00, 0x00, 0x00, 0x00, 0x00, 0x00, 0x00, 0x00, 0x00, 0x00, 0x00, 0x00, 0x0F,
0x08, 0x08, 0x08, 0x08, 0x08, 0x08, 0x08, 0x0F, 0x00, 0x00, 0x00, 0x00, 0x00, 0x00, 0x00, 0x00,
0x00, 0x00, 0x00, 0x00, 0x70, 0xF8, 0x88, 0x88, 0x98, 0x10, 0x00, 0xC0, 0xE0, 0x20, 0x20, 0xE0,
0xC0, 0x00, 0x20, 0xF0, 0xF0, 0x20, 0x20, 0x00, 0x00, 0x00, 0x00, 0x00, 0x00, 0x00, 0x00, 0xF8,
0xF8, 0x00, 0x00, 0x00, 0x00, 0x00, 0xC0, 0xE0, 0x20, 0x20, 0xE0, 0xC0, 0x00, 0xC0, 0xE0, 0x20,
0x20, 0x60, 0x40, 0x00, 0xF8, 0xF8, 0x80, 0xC0, 0x60, 0x20, 0x00, 0x00, 0x00, 0x00, 0x00, 0x00,
0x00, 0x00, 0xFC, 0xFC, 0x44, 0x44, 0xFC, 0xB8, 0x00, 0xE8, 0xE8, 0x00, 0x40, 0xE0, 0xE0, 0x40,
0x40, 0x00, 0xC0, 0xE0, 0x20, 0x20, 0x60, 0x40, 0x00, 0x00, 0x00, 0x00, 0x00, 0x00, 0x00, 0x00,
0x00, 0x00, 0x00, 0x00, 0x00, 0x00, 0x00, 0x00, 0x00, 0x00, 0x00, 0x00, 0x00, 0x00, 0x00, 0xF8,
0x08, 0x08, 0x08, 0x08, 0x08, 0x08, 0x08, 0xF8, 0x00, 0x00, 0x00, 0x00, 0x00, 0x00, 0x00, 0x00,
0x00, 0x00, 0x00, 0x00, 0x04, 0x0C, 0x08, 0x08, 0x0F, 0x07, 0x00, 0x07, 0x0F, 0x09, 0x09, 0x0D,
0x05, 0x00, 0x00, 0x07, 0x0F, 0x08, 0x08, 0x00, 0x00, 0x00, 0x00, 0x00, 0x00, 0x00, 0x00, 0x0F,
0x0F, 0x08, 0x08, 0x08, 0x08, 0x00, 0x07, 0x0F, 0x08, 0x08, 0x0F, 0x07, 0x00, 0x07, 0x0F, 0x08,
0x08, 0x0C, 0x04, 0x00, 0x0F, 0x0F, 0x03, 0x06, 0x0C, 0x08, 0x00, 0x00, 0x00, 0x00, 0x00, 0x00,
0x00, 0x00, 0x0F, 0x0F, 0x08, 0x08, 0x0F, 0x07, 0x00, 0x0F, 0x0F, 0x00, 0x00, 0x07, 0x0F, 0x08,
0x08, 0x00, 0x04, 0x0D, 0x09, 0x09, 0x0F, 0x06, 0x00, 0x00, 0x00, 0x00, 0x00, 0x00, 0x00, 0x00,
0x00, 0x00, 0x00, 0x00, 0x00, 0x00, 0x00, 0x00, 0x00, 0x00, 0x00, 0x00, 0x00, 0x00, 0x00, 0x0F,
0x08, 0x08, 0x08, 0x08, 0x08, 0x08, 0x08, 0x0F, 0x00, 0x00, 0x00, 0x00, 0x00, 0x00, 0x00, 0x00
};
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
void loop() {
  Serial.println(F("\n========================="));
  Serial.println(F("Starting EUR5A Programmer"));
  Serial.println(F("=========================\n"));
  // display
  Fill_RAM_12832(0x00);  
  ImageDisplay(startScreen);
  delay(1500);
  Fill_RAM_12832(0x00);
  ImageDisplay(Phase1);
  while (digitalRead(START_BUTTON) == HIGH) {
    // wait till pressed
  }
  /*
    1. enable program
    2. verify chip id
    3. erase 
    4. program
    5. verify
    6. Fuses
    7. Lock BitsF
  */
  digitalWrite(DUT_PWR, HIGH);
  delay(100); // wait to stabilize
  errCode = doTest();
  digitalWrite(DUT_PWR, LOW);
  delay(500);
  if (errCode) {
    handleError(errCode);
  }
  Fill_RAM_12832(0x00);
  if (!errCode) {
    ImageDisplay(completeScreen);
    delay(650);
    Fill_RAM_12832(0x00);  
    ImageDisplay(restartingScreen);
    delay(650);
  } else {
    ImageDisplay(restartingScreen);
  }
  delay(2000);
}
